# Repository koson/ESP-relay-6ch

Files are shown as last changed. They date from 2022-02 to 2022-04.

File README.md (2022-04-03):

# ESP-relay-6ch

ESP8266/ESP32 based board with 6x 24 VDC inputs and 6x 10A relay outputs.

This board is designed to be driven by an Olimex ESP32-POE, ESP32-POE-ISO or Wemos D1 Mini modules running Tasmota. In case the Wemos D1 Mini is used, the number of inputs and outputs will be limited to 4 each.

The design considers that the board will be mounted on a PCB DIN rail holder. The dimensions consider the holders offered by the Brazilian manufacturer Metaltex, check [here](https://www.metaltex.com.br/produtos/componentes/suportes/sp7-suporte-para-montagem-de-placa-de-circuito-impresso-em-trilho-din) for details.

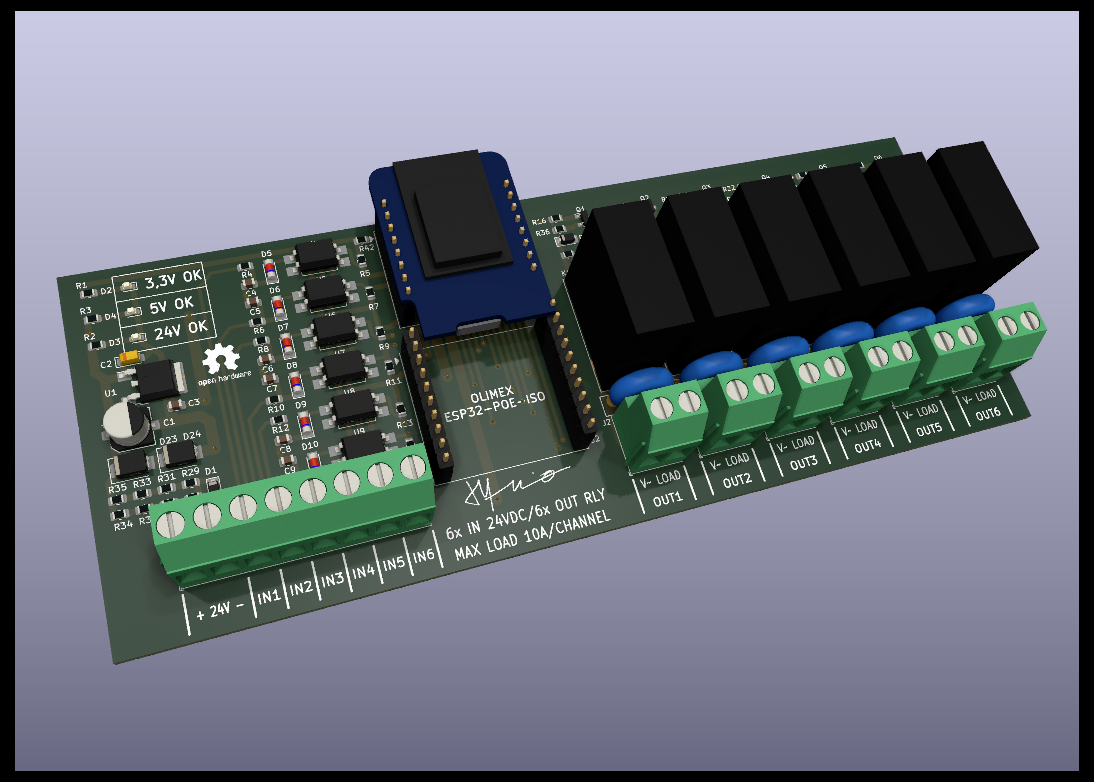
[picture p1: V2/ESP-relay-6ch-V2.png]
ESP-relay-6ch


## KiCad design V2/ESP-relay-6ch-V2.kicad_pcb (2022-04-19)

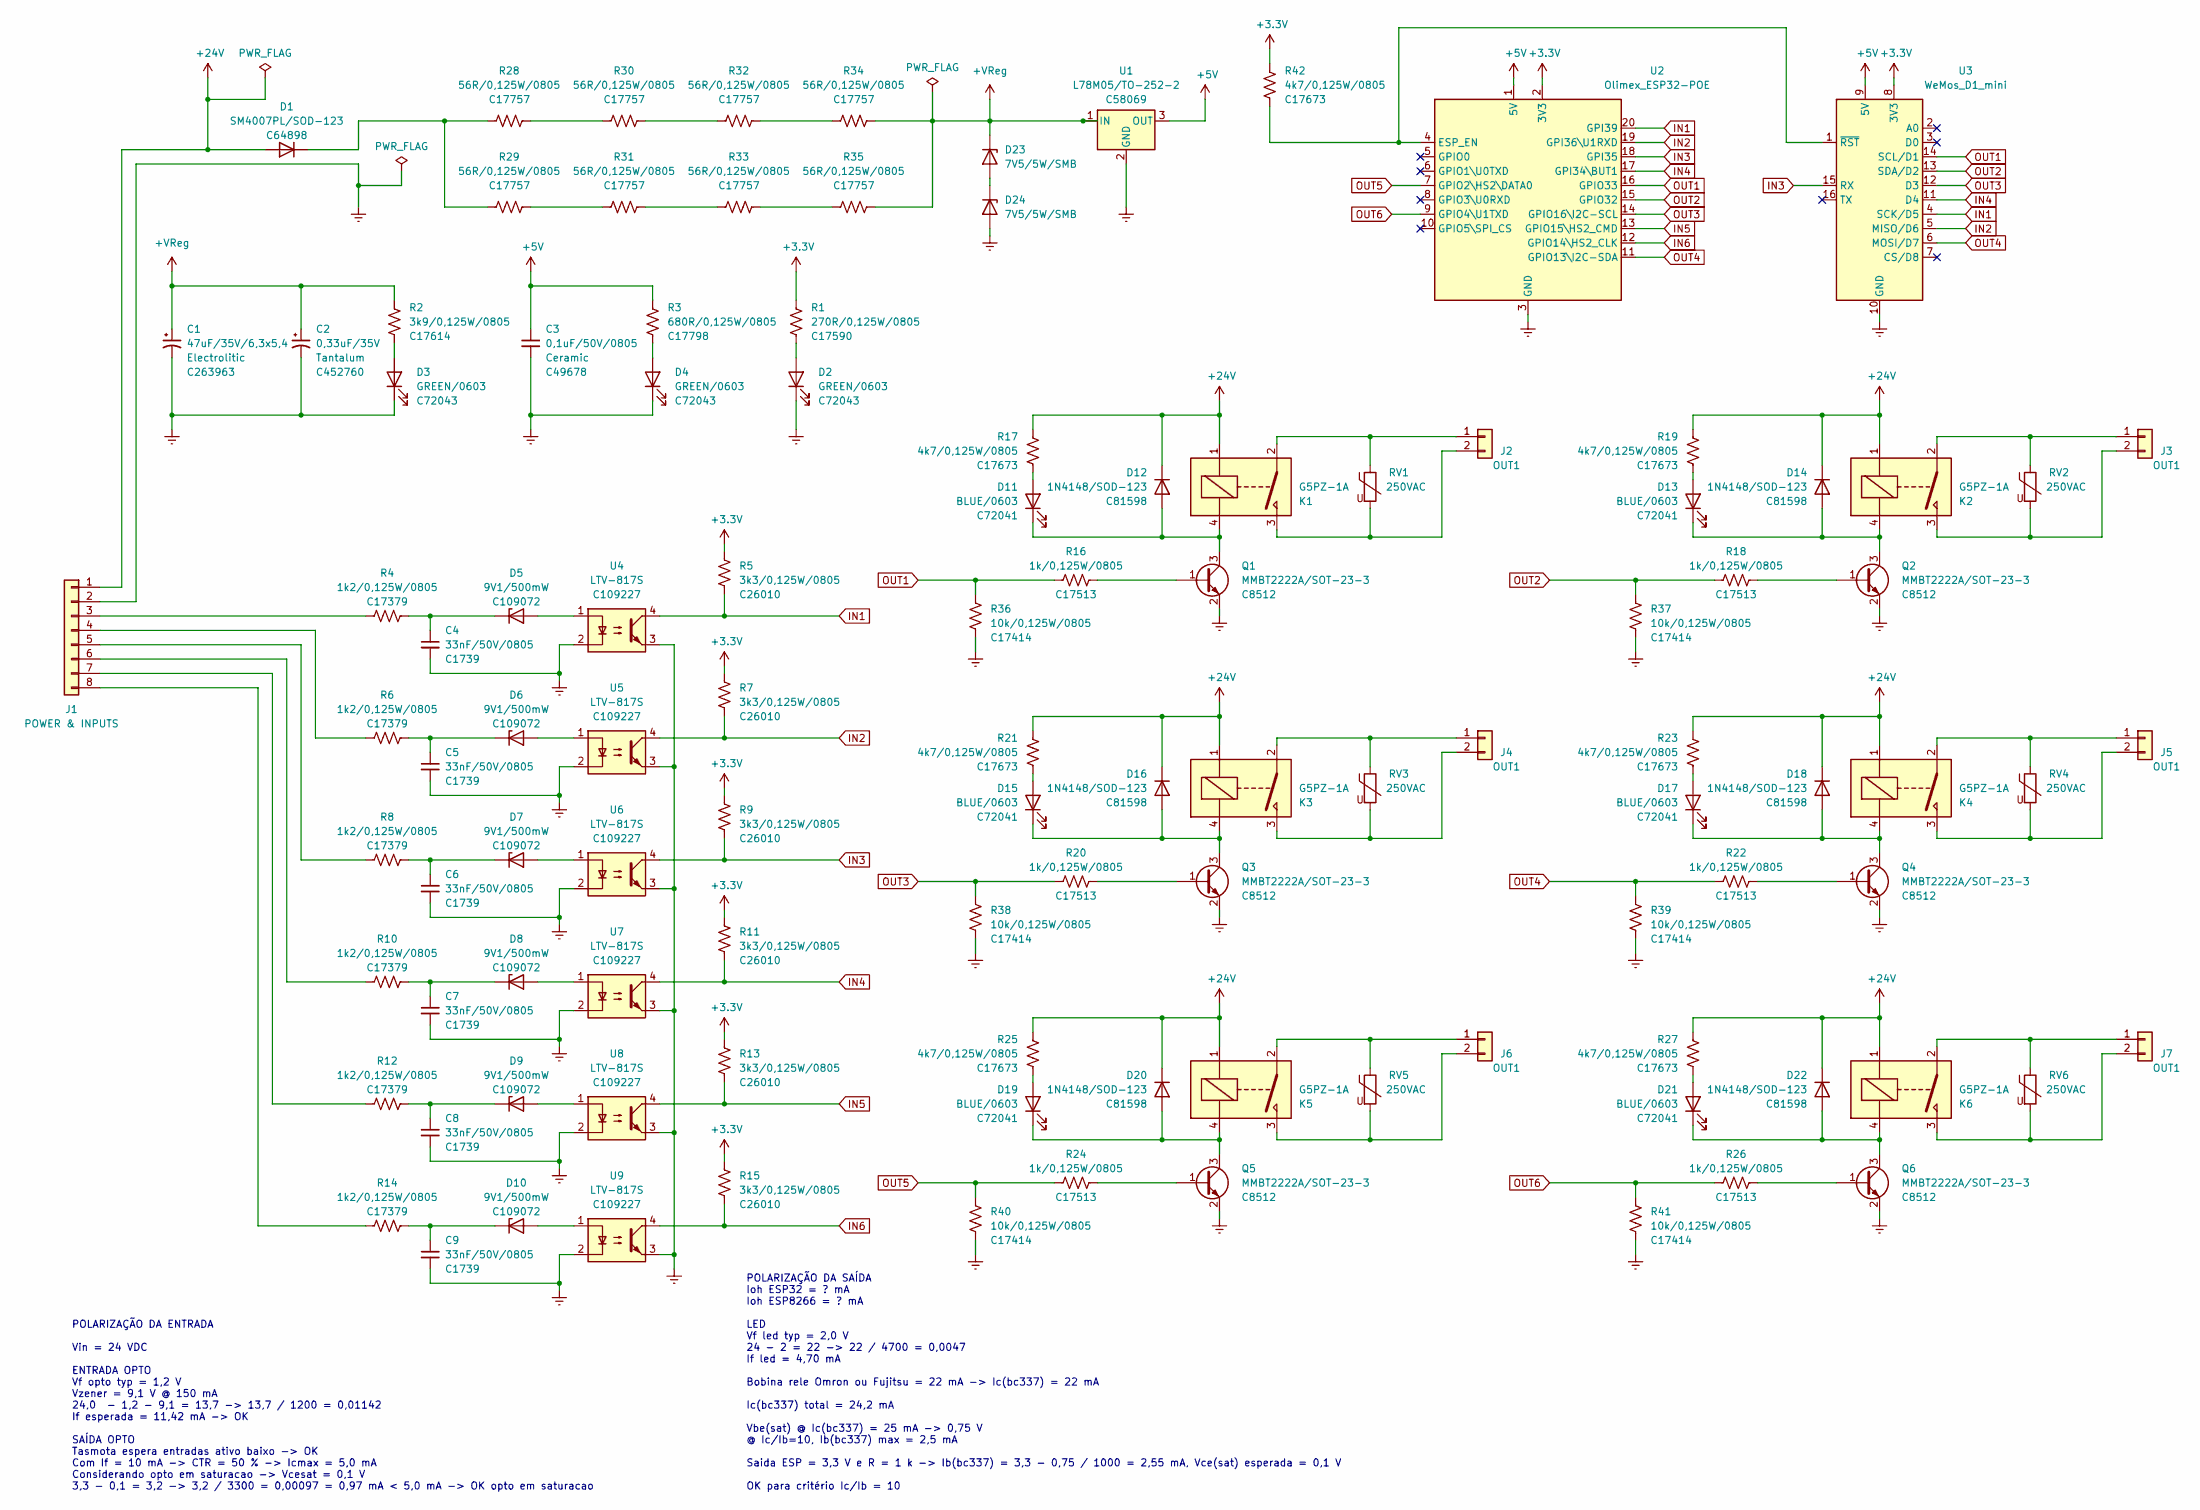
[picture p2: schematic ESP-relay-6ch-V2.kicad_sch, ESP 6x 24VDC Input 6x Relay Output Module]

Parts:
C1: 47uF/35V/6,3x5,4; CP_Elec_6.3x5.4; Mfr PN CK1V470MCRE54; JLCPCB BOM 1
C2: 0,33uF/35V; CP_EIA-3216-18_Kemet-A_Pad1.58x1.35mm_HandSolder; Mfr PN T491A334M035AT; JLCPCB BOM 1
C3: 0,1uF/50V/0805; C_0805_2012Metric; Mfr PN CC0805KRX7R9BB104; LCSC Part C49678
C4, C5, C6, C7, C8, C9: 33nF/50V/0805; C_0805_2012Metric; Mfr PN 0805B333K500NT; LCSC Part C1739
D1: SM4007PL/SOD-123; D_SOD-123; Mfr PN SM4007PL; LCSC Part C64898
D2, D3, D4: GREEN/0603; LED_0603_1608Metric; Mfr PN 19-217/GHC-YR1S2/3T; LCSC Part C72043
D5, D6, D7, D8, D9, D10: 9V1/500mW; D_MiniMELF; Mfr PN ZMM5239B; JLCPCB BOM 1
D11, D13, D15, D17, D19, D21: BLUE/0603; LED_0603_1608Metric; Mfr PN 19-217/BHC-ZL1M2RY/3T; LCSC Part C72041
D12, D14, D16, D18, D20, D22: 1N4148/SOD-123; D_SOD-123; Mfr PN 1N4148W; LCSC Part C81598
D23, D24: 7V5/5W/SMB; D_SMB; Mfr PN CZRB5343B-HF; JLCPCB BOM 0
J1: POWER & INPUTS; TerminalBlock_Phoenix_MKDS-3-8-5.08_1x08_P5.08mm_Horizontal; Mfr PN 3x BR902V; JLCPCB BOM 0
J2, J3, J4, J5, J6, J7: OUT1; TerminalBlock_Phoenix_MKDS-3-2-5.08_1x02_P5.08mm_Horizontal; Mfr PN BR902V; JLCPCB BOM 0
K1, K2, K3, K4, K5, K6: G5PZ-1A; Relay_SPST_Omron-G5PZ-1A; Mfr PN G5PZ-1A; JLCPCB BOM 0
Q1, Q2, Q3, Q4, Q5, Q6: MMBT2222A/SOT-23-3; SOT-23; Mfr PN MMBT2222A; JLCPCB BOM 1
R1: 270R/0,125W/0805; R_0805_2012Metric; Mfr PN 0805W8F2700T5E; LCSC Part C17590
R2: 3k9/0,125W/0805; R_0805_2012Metric; Mfr PN 0805W8F3901T5E; LCSC Part C17614
R3: 680R/0,125W/0805; R_0805_2012Metric; Mfr PN 0805W8F6800T5E; LCSC Part C17798
R4, R6, R8, R10, R12, R14: 1k2/0,125W/0805; R_0805_2012Metric; Mfr PN 0805W8F1201T5E; LCSC Part C17379
R5, R7, R9, R11, R13, R15: 3k3/0,125W/0805; R_0805_2012Metric; Mfr PN 0805W8F3301T5E; LCSC Part C26010
R16, R18, R20, R22, R24, R26: 1k/0,125W/0805; R_0805_2012Metric; Mfr PN 0805W8F1001T5E; LCSC Part C17513
R17, R19, R21, R23, R25, R27: 4k7/0,125W/0805; R_0805_2012Metric; Mfr PN 0805W8F4701T5E; LCSC Part C17673
R28, R29, R30, R31, R32, R33, R34, R35: 56R/0,125W/0805; R_0805_2012Metric; Mfr PN 0805W8F560JT5E; JLCPCB BOM 1
R36, R37, R38, R39, R40, R41: 10k/0,125W/0805; R_0805_2012Metric; Mfr PN 0805W8F3301T5E; LCSC Part C17414
R42: 4k7/0,125W/0805; R_0805_2012Metric; Mfr PN 0805W8F2700T5E; LCSC Part C17673
RV1, RV2, RV3, RV4, RV5, RV6: 250VAC; RV_Disc_D12mm_W3.9mm_P7.5mm; Mfr PN 391KD10; JLCPCB BOM 0
U1: L78M05/TO-252-2; TO-252-2; Mfr PN L78M05ABDT-TR; LCSC Part C58069
U2: Olimex_ESP32-POE; Olimex_ESP32-POE_Pads; Mfr PN ESP32-POE; JLCPCB BOM 0
U3: WeMos_D1_mini; WEMOS_D1_mini_light_pads; Mfr PN D1 Mini Node MCU; JLCPCB BOM 0
U4, U5, U6, U7, U8, U9: LTV-817S; SMDIP-4_W9.53mm; Mfr PN LTV-817S-TA1-C; JLCPCB BOM 1

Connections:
+3V3: R1.1, R5.1, R7.1, R9.1, R11.1, R13.1, R15.1, R42.1, U2.2 (3V3), U3.8 (3V3)
+5V: C3.1, R3.1, U1.3 (OUT), U2.1 (5V), U3.9 (5V)
+24V: D1.2 (A), D12.1 (K), D14.1 (K), D16.1 (K), D18.1 (K), D20.1 (K), D22.1 (K), J1.1, K1.1, K2.1, K3.1, K4.1, K5.1, K6.1, R17.1, R19.1, R21.1, R23.1, R25.1, R27.1
+VReg: C1.1, C2.1, D23.1 (K), R2.1, R34.2, R35.2, U1.1 (IN)
GNDREF: C1.2, C2.2, C3.2, C4.2, C5.2, C6.2, C7.2, C8.2, C9.2, D2.1 (K), D3.1 (K), D4.1 (K), D24.2 (A), J1.2, Q1.2 (E), Q2.2 (E), Q3.2 (E), Q4.2 (E), Q5.2 (E), Q6.2 (E), R36.2, R37.2, R38.2, R39.2, R40.2, R41.2, U1.2 (GND), U2.3 (GND), U3.10 (GND), U4.2, U4.3, U5.2, U5.3, U6.2, U6.3, U7.2, U7.3, U8.2, U8.3, U9.2, U9.3
IN1: R5.2, U2.20 (GPI39), U3.4 (SCK/D5), U4.4
IN2: R7.2, U2.19 (GPI36\U1RXD), U3.5 (MISO/D6), U5.4
IN3: R9.2, U2.18 (GPI35), U3.15 (RX), U6.4
IN4: R11.2, U2.17 (GPI34\BUT1), U3.11 (D4), U7.4
IN5: R13.2, U2.13 (GPIO15\HS2_CMD), U8.4
IN6: R15.2, U2.12 (GPIO14\HS2_CLK), U9.4
unnamed: C4.1, D5.1 (K), R4.1
unnamed: C5.1, D6.1 (K), R6.1
unnamed: C6.1, D7.1 (K), R8.1
unnamed: C7.1, D8.1 (K), R10.1
unnamed: C8.1, D9.1 (K), R12.1
unnamed: C9.1, D10.1 (K), R14.1
unnamed: D1.1 (K), R28.1, R29.1
unnamed: D2.2 (A), R1.2
unnamed: D3.2 (A), R2.2
unnamed: D4.2 (A), R3.2
unnamed: D5.2 (A), U4.1
unnamed: D6.2 (A), U5.1
unnamed: D7.2 (A), U6.1
unnamed: D8.2 (A), U7.1
unnamed: D9.2 (A), U8.1
unnamed: D10.2 (A), U9.1
unnamed: D11.1 (K), D12.2 (A), K1.4, Q1.3 (C)
unnamed: D11.2 (A), R17.2
unnamed: D13.1 (K), D14.2 (A), K2.4, Q2.3 (C)
unnamed: D13.2 (A), R19.2
unnamed: D15.1 (K), D16.2 (A), K3.4, Q3.3 (C)
unnamed: D15.2 (A), R21.2
unnamed: D17.1 (K), D18.2 (A), K4.4, Q4.3 (C)
unnamed: D17.2 (A), R23.2
unnamed: D19.1 (K), D20.2 (A), K5.4, Q5.3 (C)
unnamed: D19.2 (A), R25.2
unnamed: D21.1 (K), D22.2 (A), K6.4, Q6.3 (C)
unnamed: D21.2 (A), R27.2
unnamed: D23.2 (A), D24.1 (K)
unnamed: J1.3, R4.2
unnamed: J1.4, R6.2
unnamed: J1.5, R8.2
unnamed: J1.6, R10.2
unnamed: J1.7, R12.2
unnamed: J1.8, R14.2
unnamed: J2.1, K1.2, RV1.1
unnamed: J2.2, K1.3, RV1.2
unnamed: J3.1, K2.2, RV2.1
unnamed: J3.2, K2.3, RV2.2
unnamed: J4.1, K3.2, RV3.1
unnamed: J4.2, K3.3, RV3.2
unnamed: J5.1, K4.2, RV4.1
unnamed: J5.2, K4.3, RV4.2
unnamed: J6.1, K5.2, RV5.1
unnamed: J6.2, K5.3, RV5.2
unnamed: J7.1, K6.2, RV6.1
unnamed: J7.2, K6.3, RV6.2
unnamed: Q1.1 (B), R16.1
unnamed: Q2.1 (B), R18.1
unnamed: Q3.1 (B), R20.1
unnamed: Q4.1 (B), R22.1
unnamed: Q5.1 (B), R24.1
unnamed: Q6.1 (B), R26.1
unnamed: R28.2, R30.1
unnamed: R29.2, R31.1
unnamed: R30.2, R32.1
unnamed: R31.2, R33.1
unnamed: R32.2, R34.1
unnamed: R33.2, R35.1
unnamed: R42.2, U2.4 (ESP_EN), U3.1 (~RST)
OUT1: R16.2, R36.1, U2.16 (GPIO33), U3.14 (SCL/D1)
OUT2: R18.2, R37.1, U2.15 (GPIO32), U3.13 (SDA/D2)
OUT3: R20.2, R38.1, U2.14 (GPIO16\I2C-SCL), U3.12 (D3)
OUT4: R22.2, R39.1, U2.11 (GPIO13\I2C-SDA), U3.6 (MOSI/D7)
OUT5: R24.2, R40.1, U2.7 (GPIO2\HS2\DATA0)
OUT6: R26.2, R41.1, U2.9 (GPIO4\U1TXD)

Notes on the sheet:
POLARIZAÇÃO DA ENTRADA Vin = 24 VDC ENTRADA OPTO Vf opto typ = 1,2 V Vzener = 9,1 V @ 150 mA 24,0 - 1,2 - 9,1 = 13,7 -> 13,7 / 1200 = 0,01142 If esperada = 11,42 mA -> OK SAÍDA OPTO Tasmota espera entradas ativo baixo -> OK Com If = 10 mA -> CTR = 50 % -> Icmax = 5,0 mA Considerando opto em saturac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
POLARIZAÇÃO DA SAÍDA Ioh ESP32 = ? mA Ioh ESP8266 = ? mA LED Vf led typ = 2,0 V 24 - 2 = 22 -> 22 / 4700 = 0,0047 If led = 4,70 mA Bobina rele Omron ou Fujitsu = 22 mA -> Ic(bc337) = 22 mA Ic(bc337) total = 24,2 mA Vbe(sat) @ Ic(bc337) = 25 mA -> 0,75 V @ Ic/Ib=10, Ib(bc337) max = 2,5 mA Saida ESP 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

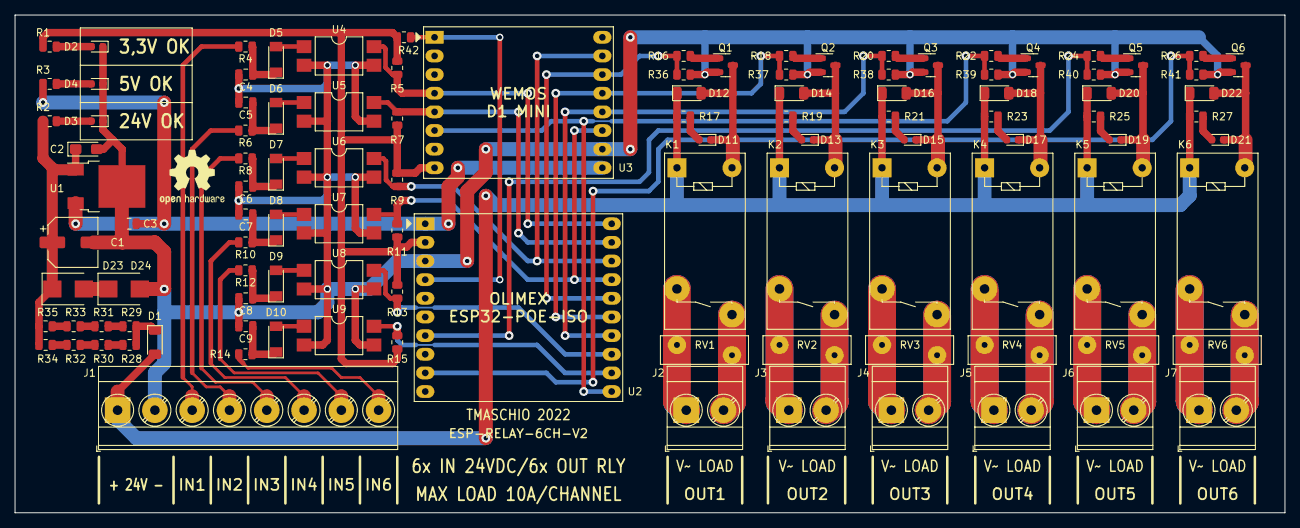
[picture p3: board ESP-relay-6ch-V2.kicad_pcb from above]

Board: 2 copper layers, 173.0 x 67.8 mm, 109 parts (0 on the bottom side), 77 nets.

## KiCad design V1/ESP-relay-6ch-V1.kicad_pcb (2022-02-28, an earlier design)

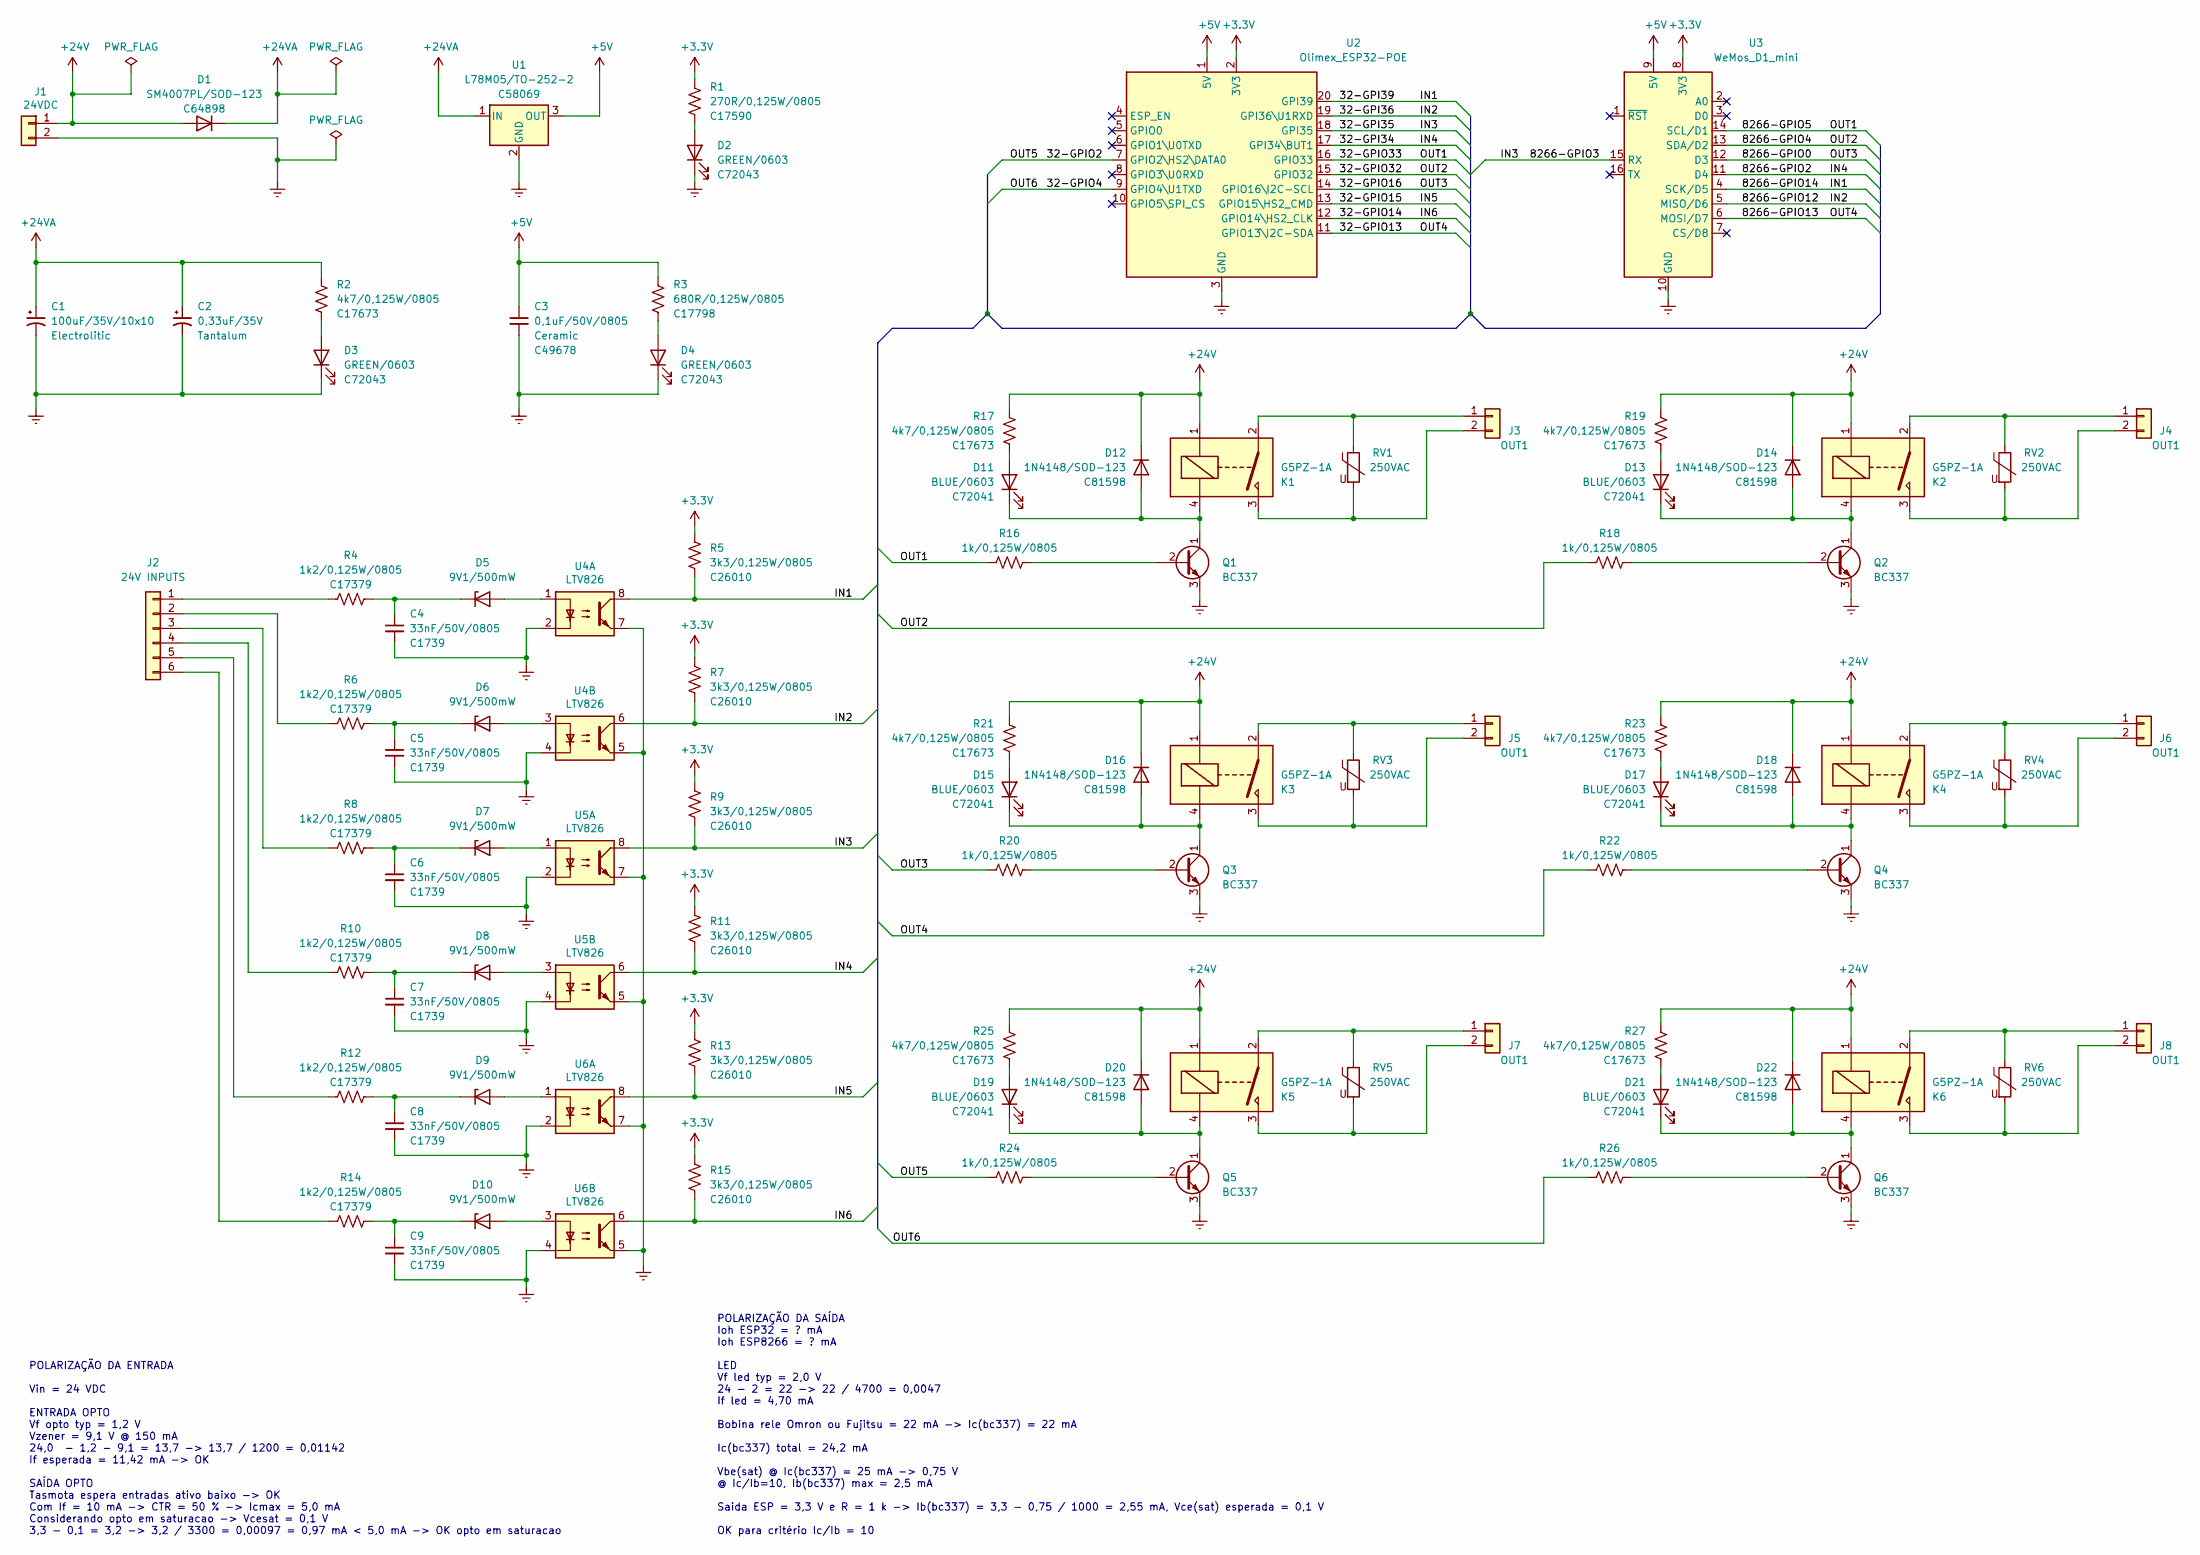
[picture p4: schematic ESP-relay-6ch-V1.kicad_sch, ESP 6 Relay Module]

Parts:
C1: 100uF/35V/10x10; CP_Elec_10x10; Mfr PN MAL214097001E3; JLCPCB BOM 0
C2: 0,33uF/35V; CP_EIA-3216-18_Kemet-A_Pad1.58x1.35mm_HandSolder; Mfr PN TAJA334K035RNJ; JLCPCB BOM 0
C3: 0,1uF/50V/0805; C_0805_2012Metric; Mfr PN CC0805KRX7R9BB104; LCSC Part C49678
C4, C5, C6, C7, C8, C9: 33nF/50V/0805; C_0805_2012Metric; Mfr PN 0805B333K500NT; LCSC Part C1739
D1: SM4007PL/SOD-123; D_SOD-123; Mfr PN SM4007PL; LCSC Part C64898
D2, D3, D4: GREEN/0603; LED_0603_1608Metric; Mfr PN 19-217/GHC-YR1S2/3T; LCSC Part C72043
D5, D6, D7, D8, D9, D10: 9V1/500mW; D_SOD-323; Mfr PN MM3Z9V1T1G; JLCPCB BOM 0
D11, D13, D15, D17, D19, D21: BLUE/0603; LED_0603_1608Metric; Mfr PN 19-217/BHC-ZL1M2RY/3T; LCSC Part C72041
D12, D14, D16, D18, D20, D22: 1N4148/SOD-123; D_SOD-123; Mfr PN 1N4148W; LCSC Part C81598
J1: 24VDC; TerminalBlock_Phoenix_MKDS-3-2-5.08_1x02_P5.08mm_Horizontal; Mfr PN BR902V; JLCPCB BOM 0
J2: 24V INPUTS; TerminalBlock_Phoenix_MKDS-3-6-5.08_1x06_P5.08mm_Horizontal; Mfr PN 3x BR902V; JLCPCB BOM 0
J3, J4, J5, J6, J7, J8: OUT1; TerminalBlock_Phoenix_MKDS-3-2-5.08_1x02_P5.08mm_Horizontal; Mfr PN BR902V; JLCPCB BOM 0
K1, K2, K3, K4, K5, K6: G5PZ-1A; Relay_SPST_Omron-G5PZ-1A; Mfr PN G5PZ-1A; JLCPCB BOM 0
Q1, Q2, Q3, Q4, Q5, Q6: BC337; TO-92_Inline_Wide; Mfr PN BC337-25; JLCPCB BOM 0
R1: 270R/0,125W/0805; R_0805_2012Metric; Mfr PN 0805W8F2700T5E; LCSC Part C17590
R2, R17, R19, R21, R23, R25, R27: 4k7/0,125W/0805; R_0805_2012Metric; Mfr PN 0805W8F4701T5E; LCSC Part C17673
R3: 680R/0,125W/0805; R_0805_2012Metric; Mfr PN 0805W8F6800T5E; LCSC Part C17798
R4, R6, R8, R10, R12, R14: 1k2/0,125W/0805; R_0805_2012Metric; Mfr PN 0805W8F1201T5E; LCSC Part C17379
R5, R7, R9, R11, R13, R15: 3k3/0,125W/0805; R_0805_2012Metric; Mfr PN 0805W8F3301T5E; LCSC Part C26010
R16, R18, R20, R22, R24, R26: 1k/0,125W/0805; R_0805_2012Metric; Mfr PN 0805W8F1001T5E; LCSC Part C17513
RV1, RV2, RV3, RV4, RV5, RV6: 250VAC; RV_Disc_D12mm_W3.9mm_P7.5mm; Mfr PN 391KD10; JLCPCB BOM 0
U1: L78M05/TO-252-2; TO-252-2; Mfr PN L78M05ABDT-TR; LCSC Part C58069
U2: Olimex_ESP32-POE; Olimex_ESP32-POE_Pads; Mfr PN ESP32-POE; JLCPCB BOM 0
U3: WeMos_D1_mini; WEMOS_D1_mini_light_pads; Mfr PN D1 Mini Node MCU; JLCPCB BOM 0
U4, U5, U6: LTV826; DIP-8_W7.62mm; Mfr PN LTV-826; JLCPCB BOM 0

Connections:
+3V3: R1.1, R5.1, R7.1, R9.1, R11.1, R13.1, R15.1, U2.2 (3V3), U3.8 (3V3)
+5V: C3.1, R3.1, U1.3 (OUT), U2.1 (5V), U3.9 (5V)
+24V: D1.2 (A), D12.1 (K), D14.1 (K), D16.1 (K), D18.1 (K), D20.1 (K), D22.1 (K), J1.1, K1.1, K2.1, K3.1, K4.1, K5.1, K6.1, R17.1, R19.1, R21.1, R23.1, R25.1, R27.1
+24VA: C1.1, C2.1, D1.1 (K), R2.1, U1.1 (IN)
/32-GPI34: R11.2, U2.17 (GPI34\BUT1), U3.11 (D4), U5.6
/32-GPI35: R9.2, U2.18 (GPI35), U3.15 (RX), U5.8
/32-GPI36: R7.2, U2.19 (GPI36\U1RXD), U3.5 (MISO/D6), U4.6
/32-GPI39: R5.2, U2.20 (GPI39), U3.4 (SCK/D5), U4.8
/32-GPIO2: R24.2, U2.7 (GPIO2\HS2\DATA0)
/32-GPIO4: R26.2, U2.9 (GPIO4\U1TXD)
/32-GPIO13: R22.2, U2.11 (GPIO13\I2C-SDA), U3.6 (MOSI/D7)
/32-GPIO14: R15.2, U2.12 (GPIO14\HS2_CLK), U6.6
/32-GPIO15: R13.2, U2.13 (GPIO15\HS2_CMD), U6.8
/32-GPIO16: R20.2, U2.14 (GPIO16\I2C-SCL), U3.12 (D3)
/32-GPIO32: R18.2, U2.15 (GPIO32), U3.13 (SDA/D2)
/32-GPIO33: R16.2, U2.16 (GPIO33), U3.14 (SCL/D1)
GNDREF: C1.2, C2.2, C3.2, C4.2, C5.2, C6.2, C7.2, C8.2, C9.2, D2.1 (K), D3.1 (K), D4.1 (K), J1.2, Q1.3 (E), Q2.3 (E), Q3.3 (E), Q4.3 (E), Q5.3 (E), Q6.3 (E), U1.2 (GND), U2.3 (GND), U3.10 (GND), U4.2, U4.4, U4.5, U4.7, U5.2, U5.4, U5.5, U5.7, U6.2, U6.4, U6.5, U6.7
unnamed: C4.1, D5.1 (K), R4.1
unnamed: C5.1, D6.1 (K), R6.1
unnamed: C6.1, D7.1 (K), R8.1
unnamed: C7.1, D8.1 (K), R10.1
unnamed: C8.1, D9.1 (K), R12.1
unnamed: C9.1, D10.1 (K), R14.1
unnamed: D2.2 (A), R1.2
unnamed: D3.2 (A), R2.2
unnamed: D4.2 (A), R3.2
unnamed: D5.2 (A), U4.1
unnamed: D6.2 (A), U4.3
unnamed: D7.2 (A), U5.1
unnamed: D8.2 (A), U5.3
unnamed: D9.2 (A), U6.1
unnamed: D10.2 (A), U6.3
unnamed: D11.1 (K), D12.2 (A), K1.4, Q1.1 (C)
unnamed: D11.2 (A), R17.2
unnamed: D13.1 (K), D14.2 (A), K2.4, Q2.1 (C)
unnamed: D13.2 (A), R19.2
unnamed: D15.1 (K), D16.2 (A), K3.4, Q3.1 (C)
unnamed: D15.2 (A), R21.2
unnamed: D17.1 (K), D18.2 (A), K4.4, Q4.1 (C)
unnamed: D17.2 (A), R23.2
unnamed: D19.1 (K), D20.2 (A), K5.4, Q5.1 (C)
unnamed: D19.2 (A), R25.2
unnamed: D21.1 (K), D22.2 (A), K6.4, Q6.1 (C)
unnamed: D21.2 (A), R27.2
unnamed: J2.1, R4.2
unnamed: J2.2, R6.2
unnamed: J2.3, R8.2
unnamed: J2.4, R10.2
unnamed: J2.5, R12.2
unnamed: J2.6, R14.2
unnamed: J3.1, K1.2, RV1.1
unnamed: J3.2, K1.3, RV1.2
unnamed: J4.1, K2.2, RV2.1
unnamed: J4.2, K2.3, RV2.2
unnamed: J5.1, K3.2, RV3.1
unnamed: J5.2, K3.3, RV3.2
unnamed: J6.1, K4.2, RV4.1
unnamed: J6.2, K4.3, RV4.2
unnamed: J7.1, K5.2, RV5.1
unnamed: J7.2, K5.3, RV5.2
unnamed: J8.1, K6.2, RV6.1
unnamed: J8.2, K6.3, RV6.2
unnamed: Q1.2 (B), R16.1
unnamed: Q2.2 (B), R18.1
unnamed: Q3.2 (B), R20.1
unnamed: Q4.2 (B), R22.1
unnamed: Q5.2 (B), R24.1
unnamed: Q6.2 (B), R26.1

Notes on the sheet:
POLARIZAÇÃO DA ENTRADA Vin = 24 VDC ENTRADA OPTO Vf opto typ = 1,2 V Vzener = 9,1 V @ 150 mA 24,0 - 1,2 - 9,1 = 13,7 -> 13,7 / 1200 = 0,01142 If esperada = 11,42 mA -> OK SAÍDA OPTO Tasmota espera entradas ativo baixo -> OK Com If = 10 mA -> CTR = 50 % -> Icmax = 5,0 mA Considerando opto em saturac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
POLARIZAÇÃO DA SAÍDA Ioh ESP32 = ? mA Ioh ESP8266 = ? mA LED Vf led typ = 2,0 V 24 - 2 = 22 -> 22 / 4700 = 0,0047 If led = 4,70 mA Bobina rele Omron ou Fujitsu = 22 mA -> Ic(bc337) = 22 mA Ic(bc337) total = 24,2 mA Vbe(sat) @ Ic(bc337) = 25 mA -> 0,75 V @ Ic/Ib=10, Ib(bc337) max = 2,5 mA Saida ESP 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

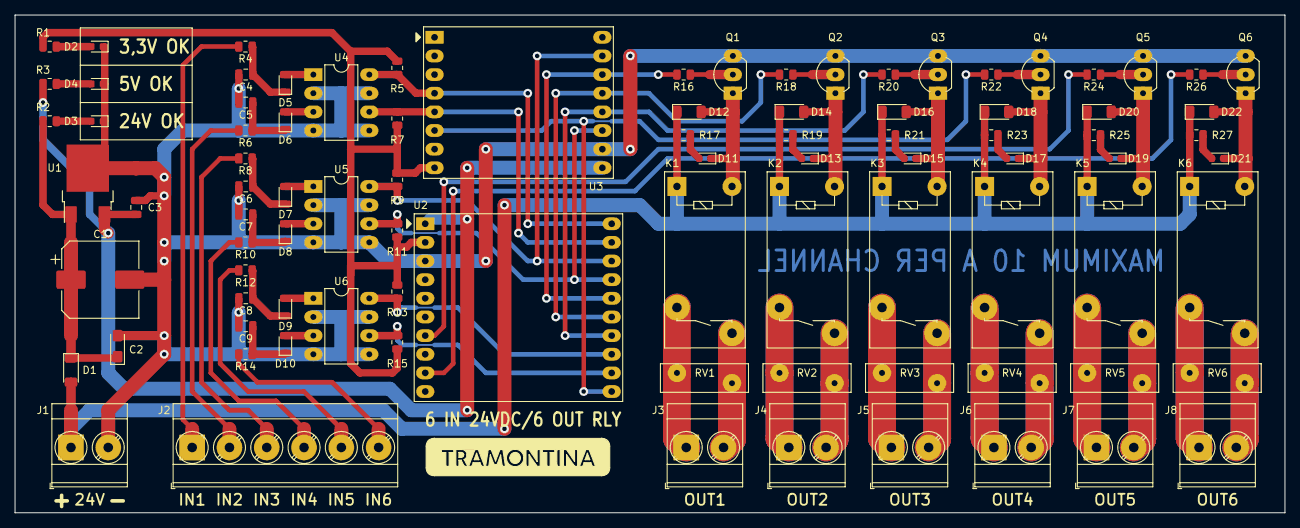
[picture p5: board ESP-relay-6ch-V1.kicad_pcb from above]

Board: 2 copper layers, 173.0 x 67.8 mm, 90 parts (0 on the bottom side), 68 nets.

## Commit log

2022-02-02 Initial upload
    [ESP-relay_6ch-V1-B_Cu.gbr, ESP-relay_6ch-V1-B_Mask.gbr, ESP-relay_6ch-V1-Edge_Cuts.gbr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]
2022-02-28 Cleanup after migration to Kicad 6
    [ESP-relay_6ch-V1.kicad_pcb, ESP-relay_6ch-V1.sch]
2022-03-06 V2 development
    [ESP-relay_6ch-V1-B_Cu.gbr, ESP-relay_6ch-V1-B_Mask.gbr, ESP-relay_6ch-V1-Edge_Cuts.gbr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]
2022-03-06 cleaning up
    [ESP-relay_6ch-V1-B_Cu.gbr, ESP-relay_6ch-V1-B_Mask.gbr, ESP-relay_6ch-V1-Edge_Cuts.gbr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]
2022-03-07 footprint updates
    [ESP-relay_6ch-V2.kicad_pcb, ESP-relay_6ch-V2.kicad_sch]
2022-03-29 work in progress
    [ESP-relay_6ch-V2.kicad_pcb, ESP-relay_6ch-V2.kicad_sch]
2022-04-01 add pull down resistors
    [ESP-relay_6ch-V2.kicad_pcb, ESP-relay_6ch-V2.kicad_sch]
2022-04-01 PCB tweaks
    [ESP-relay_6ch-V2.kicad_pcb, ESP-relay_6ch-V2.kicad_sch]
2022-04-03 rename files to new schema
    [ESP-relay-6ch-V1.kicad_pcb, ESP-relay-6ch-V1.kicad_sch, ESP-relay-6ch-V2.kicad_pcb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]
2022-04-13 update schematics title block
    [ESP-relay-6ch-V2.kicad_pcb, ESP-relay-6ch-V2.kicad_sch]
